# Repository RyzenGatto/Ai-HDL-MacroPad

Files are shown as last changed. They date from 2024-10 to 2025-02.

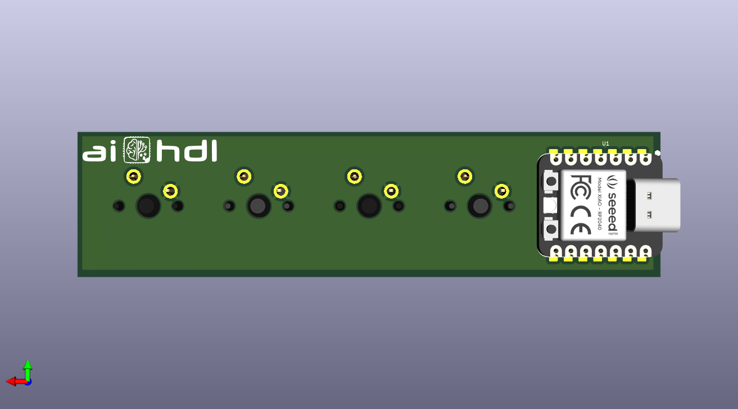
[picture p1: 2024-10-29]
Pictures/V1.0 PRISM Macro Pad_Rear.png

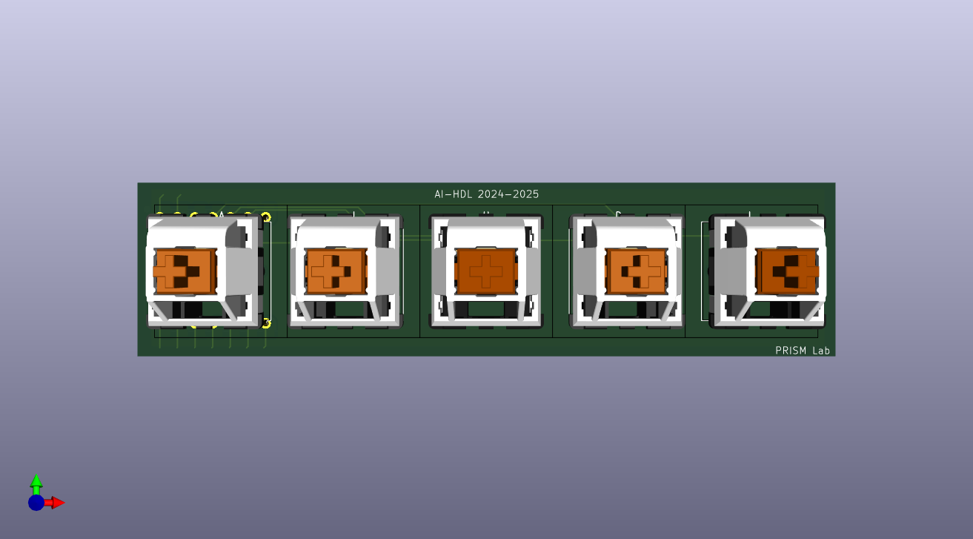
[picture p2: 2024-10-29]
Pictures/V1.0 PRISM Macro Pad_Front.png

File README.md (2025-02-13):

# AI-HDL-MacroPad
Application Specific nRF52840 OR RP2040 based Keyboards for the PRISM Lab at the University of Arizona

Below are 3D renders. Schematic for the latest version is available in the Repo.

NOTE: If you want to adapt this to your own project with more keys, get familiar with KiCad and learn keyboard matrices (KMK has a good guide in their repo). 

## Info

KiCad files can be found in its folder. Production files can be found in Export Files. Version 1 is a super simple 5-key design for use with a XIAO RP2040. It does not have Bluetooth. It's also much cheaper. 
Version 1.5 has BT and a lithium-ion battery and relies on the KMK firmware.

## Version 2.4 
Fully integrated Macro Design. This design has been optimized for long-term reliability and has been simplified. A test PCB is accessible in the V2 kicad folders





## Old Versions
**Version 1**
This is the cheapest version. It can be assembled by hand, no BOM or pick and place needed.
V1 0 PRISM Macro Pad_Front

**Version 1.5**
Basically V1 but with BLE and a battery and M2 2.2mm screws.
V1 5 MacroPad Front

V1 5 MacroPad Rear

V1 5 Schematic

**Version 2.3 (Test PCB)**
2 xx Front

2 xx back

# TO DO

1. Write software using KMK firmware

~~2. Determine Key Caps~~ DONE

~~3. Develop wifi version with battery + BT~~ DONE

4.  PROTOTYPE!

# Materials
ONLY FOR V1.5
| Item  | Quantity | Link |
| --- | --- | ---- |
| seeed studio XIAO nRF52840  | 1  | [Mouser](https://www.mouser.com/ProductDetail/Seeed-Studio/102010448?qs=Znm5pLBrcAJ5g%252BWAkitg4w%3D%3D) |
| Cherry MX Switches  | 6  |  [Mouser](https://www.mouser.com/ProductDetail/CHERRY/MX1A-C1NW?qs=sGAEpiMZZMtFyPk3yBMYYJ6eFtqPPgccKDEfiw%252Brqds%3D) |
| Lithium-Ion Battery | 1 | [Option 1](https://www.digikey.com/en/products/detail/sparkfun-electronics/PRT-13851/6605199) [Option 2](https://www.digikey.com/en/products/detail/adafruit-industries-llc/258/5054544) |
| Battery connector | 1 | [Mouser](https://www.digikey.com/en/products/detail/jst-sales-america-inc/S2B-PH-K-S/926626) |
| Battery LED | 1 | [Mouser](https://www.digikey.com/en/products/detail/sparkfun-electronics/COM-16347/11630204)

2.xx Materials are available in the BOM of the KiCad Files.

# Firmware

This project will use the [KMK Firmware](https://github.com/KMKfw/kmk_firmware).
KMK has its own license, please refer to their page for more details. KMK has a GUI interface that another developer made.

This [battery management](https://github.com/Tjoms99/xiao_sense_nrf52840_battery_lib) software will be used to communicate battery life and charge status to the user.

Software by [this guy](https://github.com/ernesto-martinez1)

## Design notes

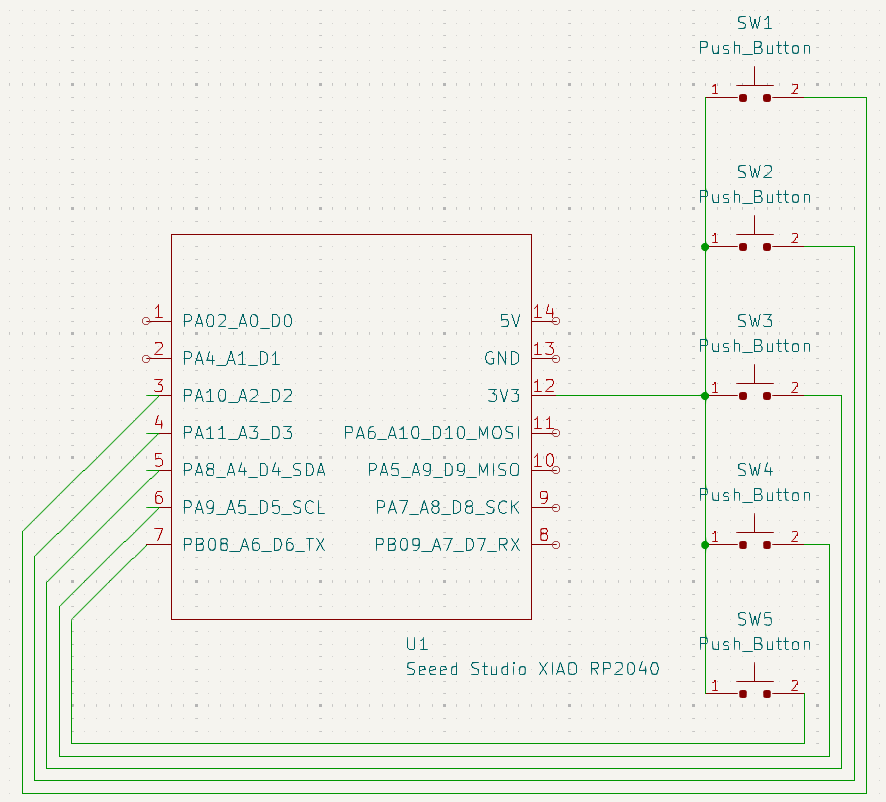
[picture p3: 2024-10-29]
Pictures/V1.0 Schematic.PNG

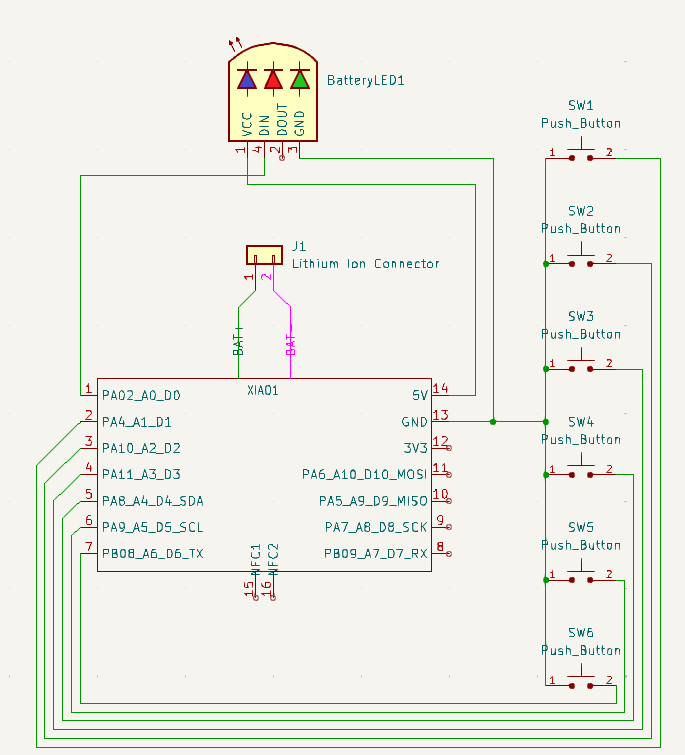
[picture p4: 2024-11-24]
Pictures/V1.5 Schematic.PNG

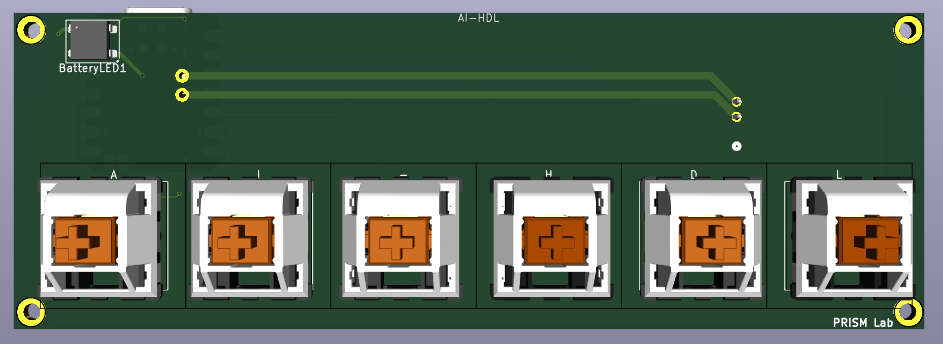
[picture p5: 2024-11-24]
Pictures/V1.5 MacroPad Front.PNG

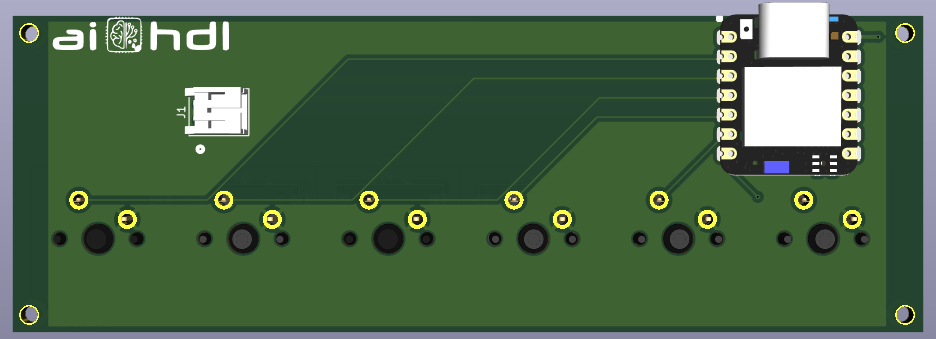
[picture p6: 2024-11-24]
Pictures/V1.5 MacroPad Rear.PNG

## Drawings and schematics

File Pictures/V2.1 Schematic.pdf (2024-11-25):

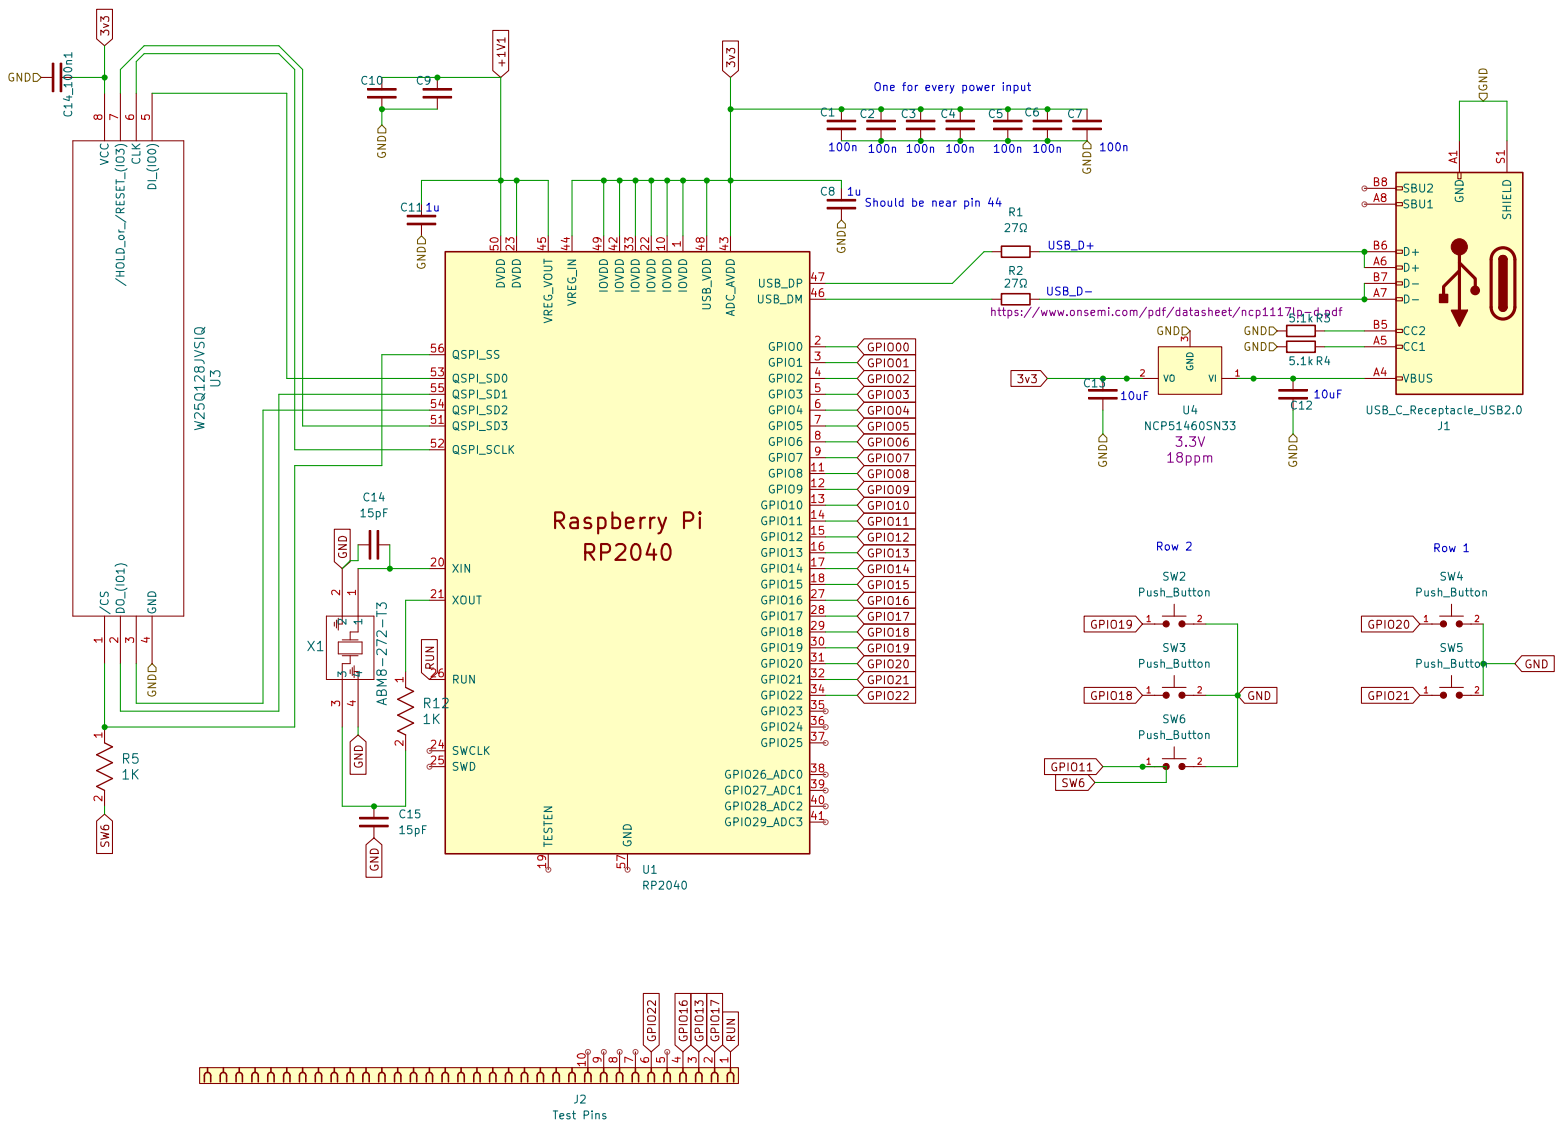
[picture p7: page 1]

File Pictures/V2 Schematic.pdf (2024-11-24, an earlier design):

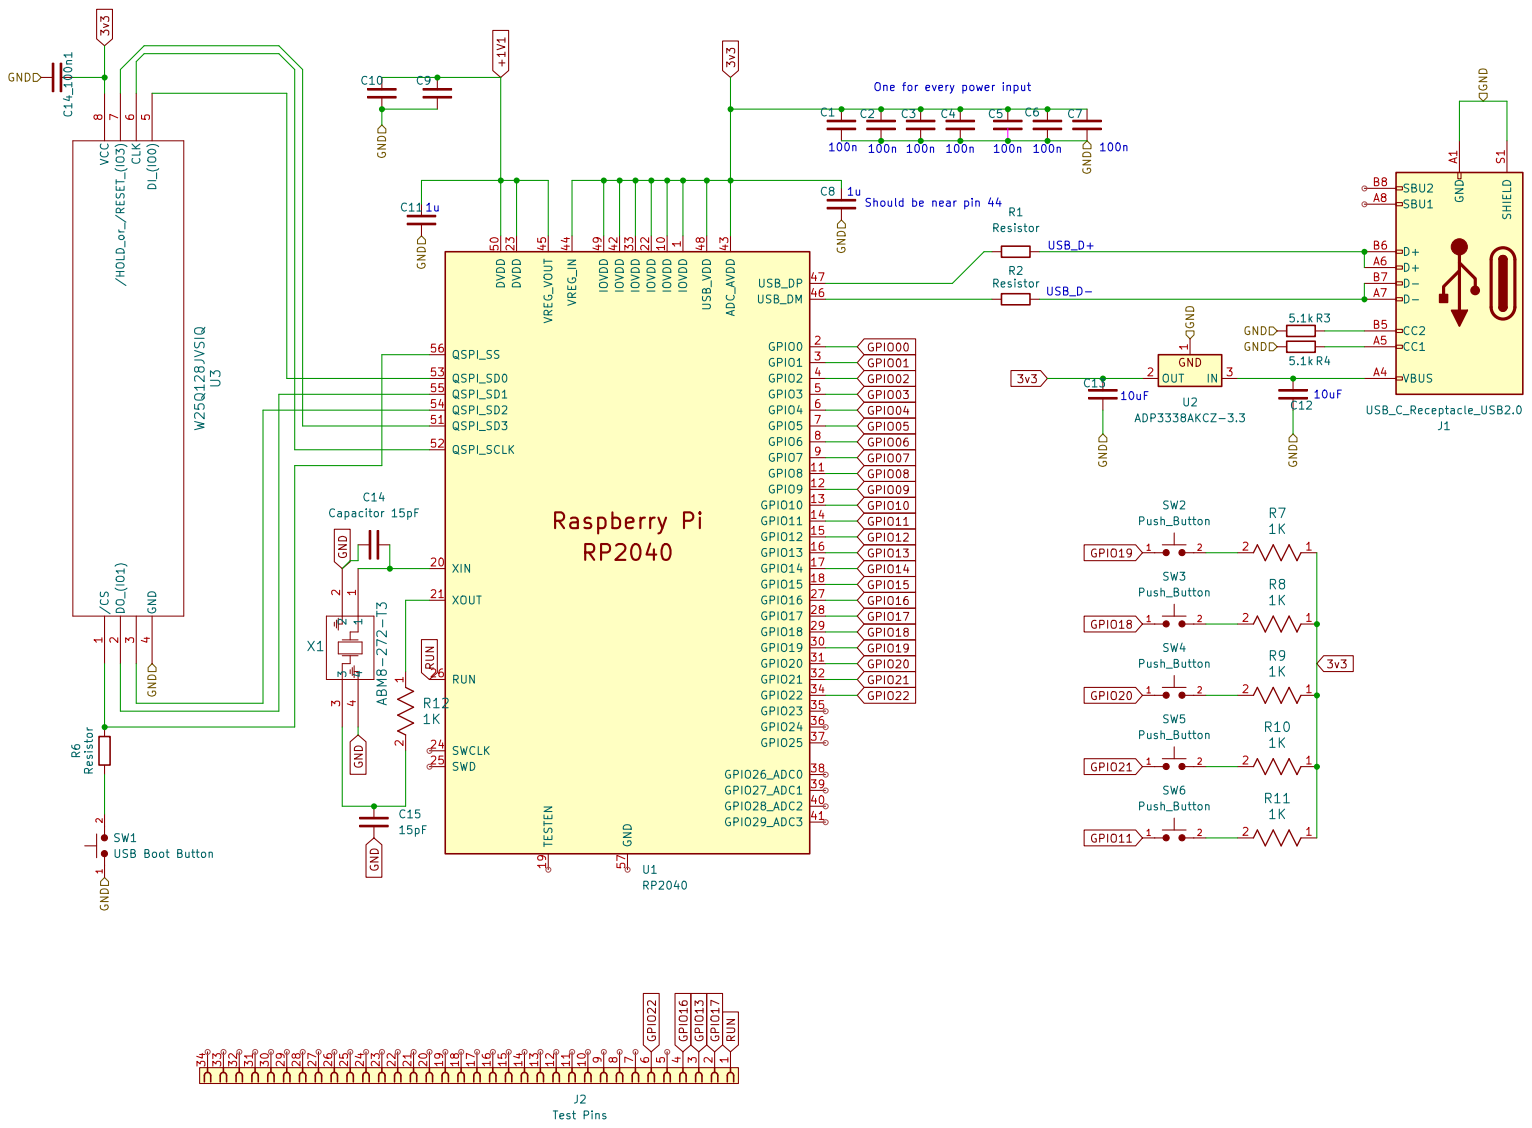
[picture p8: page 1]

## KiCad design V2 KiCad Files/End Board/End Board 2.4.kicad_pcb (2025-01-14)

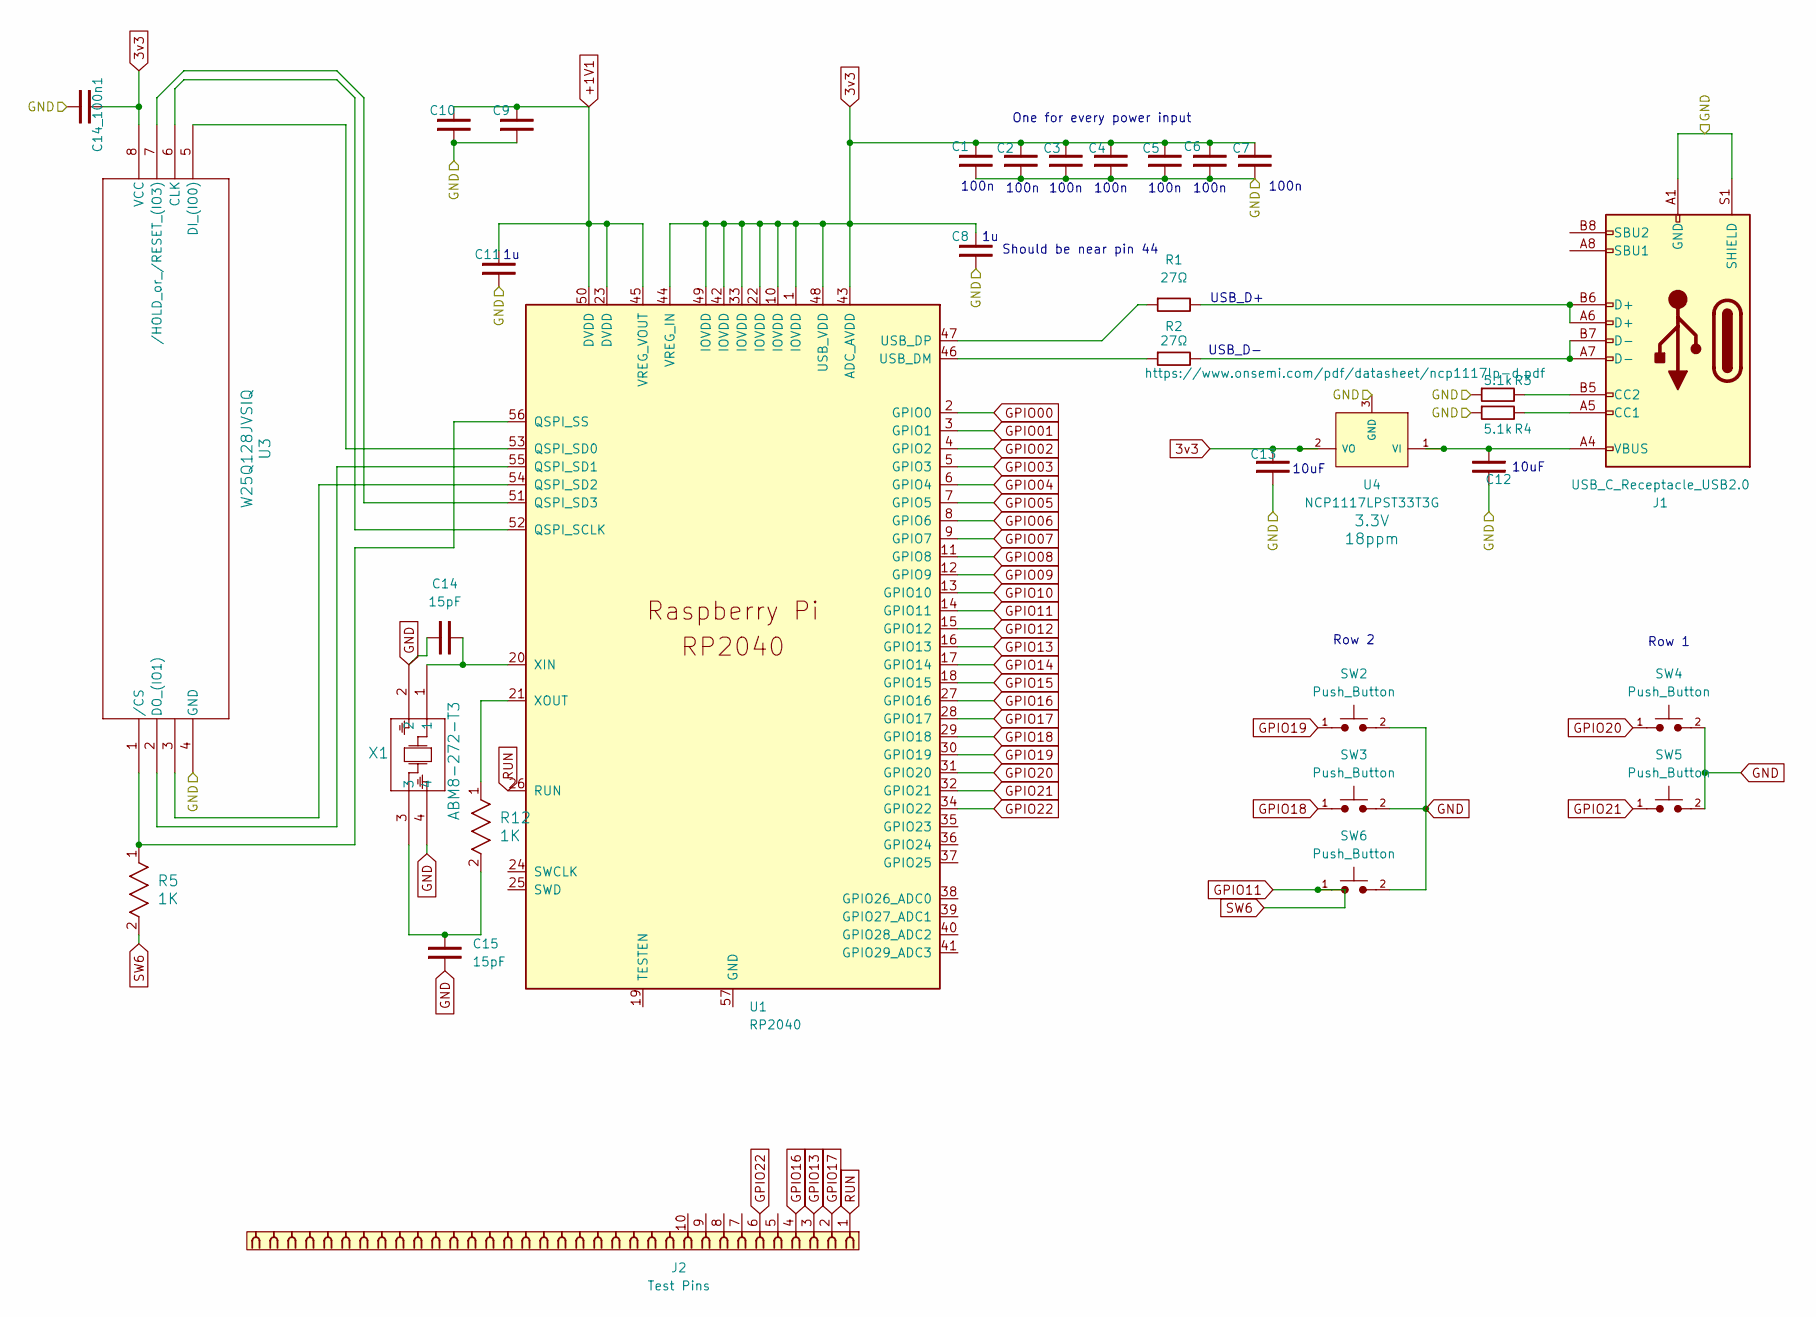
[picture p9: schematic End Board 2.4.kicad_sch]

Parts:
C1, C2, C3, C4, C5, C6, C7, C9, C10, C14_100n1: 100nF; C_0603_1608Metric; Part Number CL10E104KC8VPNC
C8, C11: 1uF; C_0603_1608Metric; Part Number CL10B105KP8NNNC
C12, C13: 10uF; C_0603_1608Metric; Part Number CL10A106MQ8NNNC
C14, C15: 15pF; C_0603_1608Metric; Part Number 885012006003
J1: USB_C_Receptacle_USB2.0; USB_C_Receptacle_G-Switch_GT-USB-7010ASV; Part Number GT-USB-7010ASV; LCSC C165948
J2: Test Pins
R1, R2: 27Ω; R_0402_1005Metric; Part Number ERJ-2RKF27R0X
R3, R4: 5.1k; R_0402_1005Metric; Part Number ERA-2AEB512X
R5, R12: 1K; RC0402N_PAN; Part Number ERJ-2RKF1001X
SW2, SW3, SW4, SW5, SW6: Push_Button; SW_Cherry_MX_1.00u_PCB; Part Number MX1A-C1NW
U1: RP2040; RP2040-QFN-56; Part Number SC0914(13)
U3: W25Q128JVSIQ; SOIC-8-1EP_3.9x4.9mm_P1.27mm_EP2.29x3mm; Part Number W25Q128JVSIQ
U4: NCP1117LPST33T3G; NCP1117; Part Number NCP1117LPST33T3G; JLCPCB ID C233715
X1: ABM8-272-T3; ABM8-272-T3_ABR; Part Number ABM8-272-T3

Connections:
3v3: C1.2, C2.2, C3.2, C4.2, C5.2, C6.2, C7.2, C8.2, C13.2, C14_100n1.2, U1.1 (IOVDD), U1.10 (IOVDD), U1.22 (IOVDD), U1.33 (IOVDD), U1.42 (IOVDD), U1.43 (ADC_AVDD), U1.44 (VREG_IN), U1.48 (USB_VDD), U1.49 (IOVDD), U3.8 (VCC), U4.2 (VO)
+1V1: C9.2, C10.2, C11.2, U1.23 (DVDD), U1.45 (VREG_VOUT), U1.50 (DVDD)
GND: C1.1, C2.1, C3.1, C4.1, C5.1, C6.1, C7.1, C8.1, C9.1, C10.1, C11.1, C12.2, C13.1, C14.1, C14_100n1.1, C15.1, J1.A1 (GND), J1.A12 (GND), J1.B1 (GND), J1.B12 (GND), J1.S1 (SHIELD), R3.1, R4.1, SW2.2, SW3.2, SW4.2, SW5.2, SW6.2, U1.57 (GND), U3.4 (GND), U4.3 (GND), X1.2, X1.4
GPIO00: U1.2 (GPIO0)
GPIO01: U1.3 (GPIO1)
GPIO02: U1.4 (GPIO2)
GPIO03: U1.5 (GPIO3)
GPIO04: U1.6 (GPIO4)
GPIO05: U1.7 (GPIO5)
GPIO06: U1.8 (GPIO6)
GPIO07: U1.9 (GPIO7)
GPIO08: U1.11 (GPIO8)
GPIO09: U1.12 (GPIO9)
GPIO10: U1.13 (GPIO10)
GPIO11: R5.2, SW6.1, U1.14 (GPIO11)
GPIO12: U1.15 (GPIO12)
GPIO13: J2.3, U1.16 (GPIO13)
GPIO14: U1.17 (GPIO14)
GPIO15: U1.18 (GPIO15)
GPIO16: J2.4, U1.27 (GPIO16)
GPIO17: J2.2, U1.28 (GPIO17)
GPIO18: SW3.1, U1.29 (GPIO18)
GPIO19: SW2.1, U1.30 (GPIO19)
GPIO20: SW4.1, U1.31 (GPIO20)
GPIO21: SW5.1, U1.32 (GPIO21)
GPIO22: J2.6, U1.34 (GPIO22)
unnamed: C15.2, R12.2, X1.3
unnamed: J1.A5 (CC1), R4.2
unnamed: J1.B5 (CC2), R3.2
unnamed: J1.A6 (D+), J1.B6 (D+), R1.2
unnamed: J1.A7 (D-), J1.B7 (D-), R2.2
unnamed: U1.52 (QSPI_SCLK), U3.6 (CLK)
unnamed: U1.53 (QSPI_SD0), U3.5 (DI_(IO0))
unnamed: U1.55 (QSPI_SD1), U3.2 (DO_(IO1))
unnamed: U1.54 (QSPI_SD2), U3.3
unnamed: U1.51 (QSPI_SD3), U3.7 (/HOLD_or_/RESET_(IO3))
unnamed: R5.1, U1.56 (QSPI_SS), U3.1 (/CS)
unnamed: R2.1, U1.46 (USB_DM)
unnamed: R1.1, U1.47 (USB_DP)
unnamed: C14.2, U1.20 (XIN), X1.1
unnamed: R12.1, U1.21 (XOUT)
unnamed: C12.1, J1.A4 (VBUS), J1.A9 (VBUS), J1.B4 (VBUS), J1.B9 (VBUS), U4.1 (VI)
RUN: J2.1, U1.26 (RUN)

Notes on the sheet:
100n
One for every power input
Should be near pin 44
10uF
Row 1
Row 2
USB_D-
USB_D+

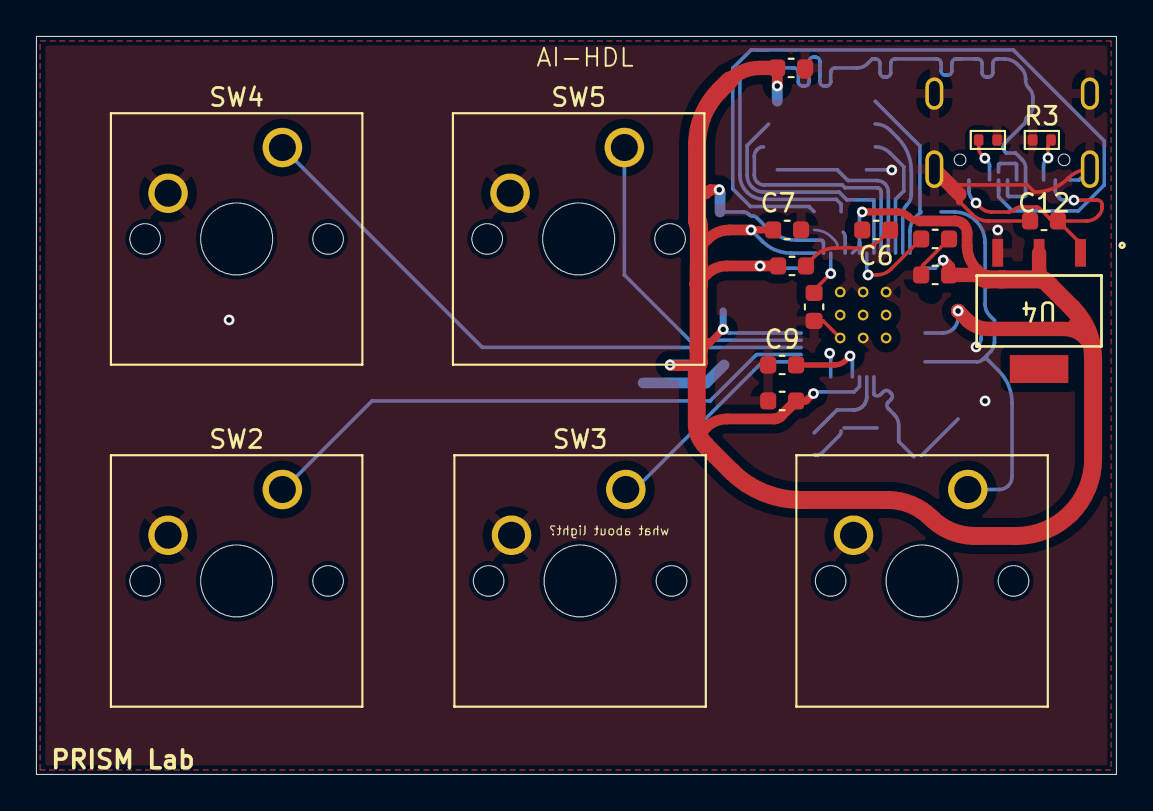
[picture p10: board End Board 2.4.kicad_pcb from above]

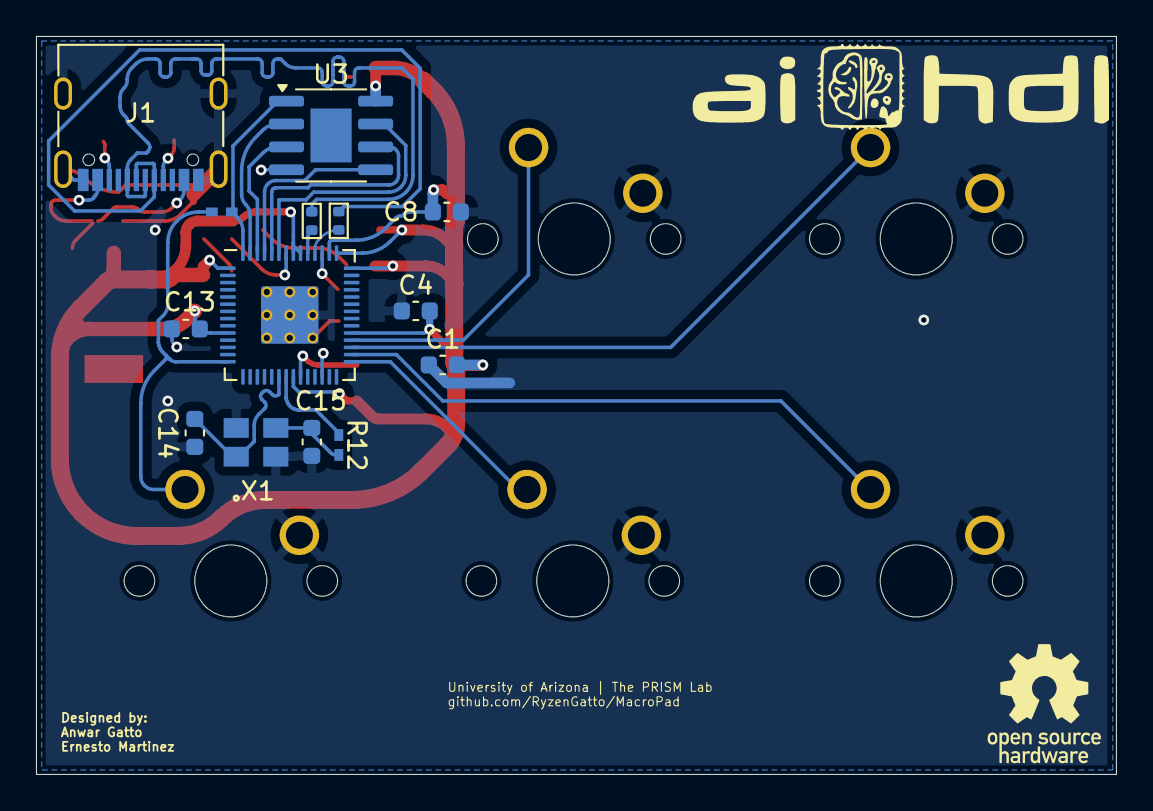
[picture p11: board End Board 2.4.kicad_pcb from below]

Board: 2 copper layers, 60.0 x 41.0 mm, 32 parts (14 on the bottom side), 24 nets.

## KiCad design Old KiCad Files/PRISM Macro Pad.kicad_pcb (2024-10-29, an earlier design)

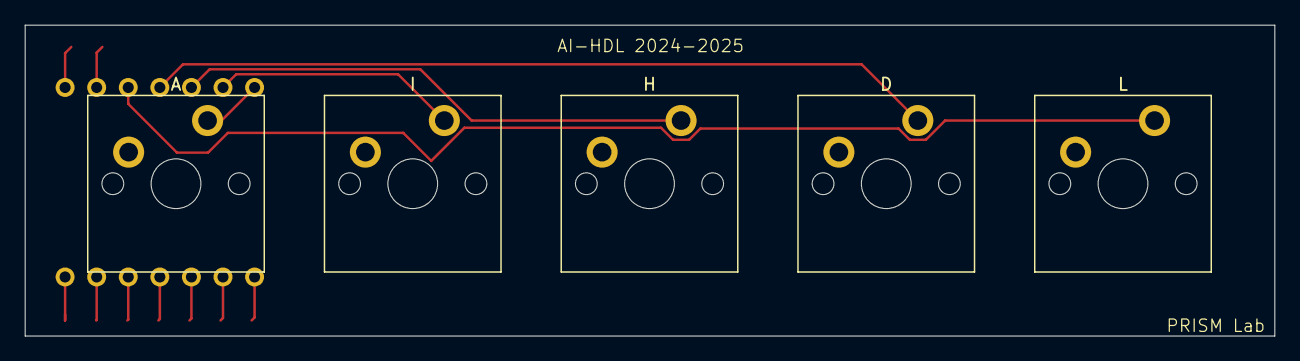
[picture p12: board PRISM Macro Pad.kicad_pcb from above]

Board: 2 copper layers, 100.5 x 25.0 mm, 6 parts (1 on the bottom side), 6 nets.

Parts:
A: Push_Button; SW_Cherry_MX_PCB_1.00u
D: Push_Button; SW_Cherry_MX_PCB_1.00u
H: Push_Button; SW_Cherry_MX_PCB_1.00u
I: Push_Button; SW_Cherry_MX_PCB_1.00u
L: Push_Button; SW_Cherry_MX_PCB_1.00u
U1: Seeed Studio XIAO RP2040; XIAO-RP2040-DIP

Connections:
unnamed: A.1, D.1, H.1, I.1, L.1, U1.12 (3V3)
unnamed: H.2, U1.5 (PA8_A4_D4_SDA)
unnamed: I.2, U1.6 (PA9_A5_D5_SCL)
unnamed: L.2, U1.3 (PA10_A2_D2)
unnamed: D.2, U1.4 (PA11_A3_D3)
unnamed: A.2, U1.7 (PB08_A6_D6_TX)
